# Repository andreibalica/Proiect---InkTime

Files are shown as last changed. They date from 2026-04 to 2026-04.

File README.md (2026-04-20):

# InkTime Smartwatch - Documentatie Hardware

Acest repository contine fisierele de proiectare hardware (scheme electronice, layout PCB) pentru InkTime, un smartwatch open-source. Proiectul este axat pe eficientizarea consumului energetic si integrarea unui afisaj bi-stabil.

## 1. Principiu de Functionare si Eficienta Energetica

Sistemul elimina limitarile de autonomie specifice smartwatch-urilor clasice prin utilizarea unui ecran tip E-Paper (electroforetic). 

Datorita proprietatii de bi-stabilitate, matricea display-ului isi pastreaza starea fara a necesita alimentare continua. Consumul de energie are loc exclusiv pe durata ciclului de refresh (schimbarea informatiei afisate). Aceasta caracteristica tehnica permite microcontroller-ului sa ramana in modul "Deep Sleep" pe perioade lungi, asigurand o autonomie extinsa si eliminand totodata necesitatea iluminarii de fundal (Backlight).

## 2. Subsisteme Componente

Arhitectura sistemului este impartita in urmatoarele blocuri functionale majore:

* **Microcontroller (MCU):** Implementat in jurul SoC-ului nRF52840 (Nordic Semiconductor). Ofera suport nativ pentru protocolul Bluetooth 5.0 (BLE) si asigura procesarea generala, gestionand atat magistralele de date, cat si modurile de operare ultra-low power.
* **Power Management Unit (PMU):**
  * **Circuit de Incarcare:** Controller dedicat pe portul USB-C, echipat cu protectie la supratensiune si descarcari electrostatice (ESD / diode TVS).
  * **Regulator DC/DC:** Ofera o tensiune stabilizata de 3.3V necesara liniilor digitale, compensand variatiile de tensiune ale acumulatorului LiPo.
  * **Fuel Gauge:** Integrat de masurare a capacitatii reziduale (State of Charge). Citeste datele celulei LiPo fara a necesita un rezistor de shunt si raporteaza valorile prin I2C.
* **Senzoristica si Interfata Utilizator:**
  * **IMU (Inertial Measurement Unit):** Senzor accelerometric utilizat pentru numararea pasilor si detectia gestului de activare a ecranului.
  * **Driver Haptic:** Asigura comanda prin PWM a motorului de vibratii pentru generarea alertelor tactile.
  * **Input Hardware:** Trei butoane mecanice conectate pe porturile GPIO pentru operarea dispozitivului.

## 3. Interfete de Comunicatie

Comunicatia in interiorul sistemului este structurata pentru a separa transferul de date rapid de citirea senzorilor:

* **Magistrala SPI:** Alocata strict modulului E-Paper. Faciliteaza transferul rapid de date catre controller-ul de display pe parcursul refresh-ului.
* **Magistrala I2C:** Utilizata ca port comun de comunicatie pentru senzorul IMU, integratul Fuel Gauge si driver-ul haptic.
* **Semnale EXTI (Intreruperi):** Butoanele mecanice si pinul de interrupt al senzorului IMU trezesc in mod direct microcontroller-ul din starea de repaus atunci cand se inregistreaza un eveniment fizic.

## 4. Note de Fabricatie si Asamblare (PCBA)

Acest repository include fisierele de productie (Gerber / Pick and Place) si lista de materiale (BOM) necesare pentru fabricarea placii. Pentru a garanta functionarea la parametri optimi a ansamblului, procesul de productie trebuie sa respecte urmatoarele cerinte tehnice:

* **Grosime Substrat:** Placa de baza (PCB) trebuie fabricata cu o grosime stricta de 1.0mm. Utilizarea grosimii standard de 1.6mm va compromite asamblarea mecanica in interiorul carcasei printate 3D.
* **Optimizare PCBA:** Designul a fost conceput pentru a facilita productia automatizata. Toate componentele SMD sunt plasate exclusiv pe stratul superior (TOP Layer), reducand atat complexitatea, cat si costurile procesului de asamblare.
* **Integritate RF si Rutare:** S-a implementat tehnica de "via stitching" intre planurile de masa (TOP si BOTTOM) in vecinatatea circuitului radio. Acest detaliu este critic pentru performanta antenei ceramice la 2.4GHz. De asemenea, erorile de tip "Board Outline Clearance" din zona antenei sunt intentionate, antena necesitand lipsa totala a cuprului pe layerele adiacente.

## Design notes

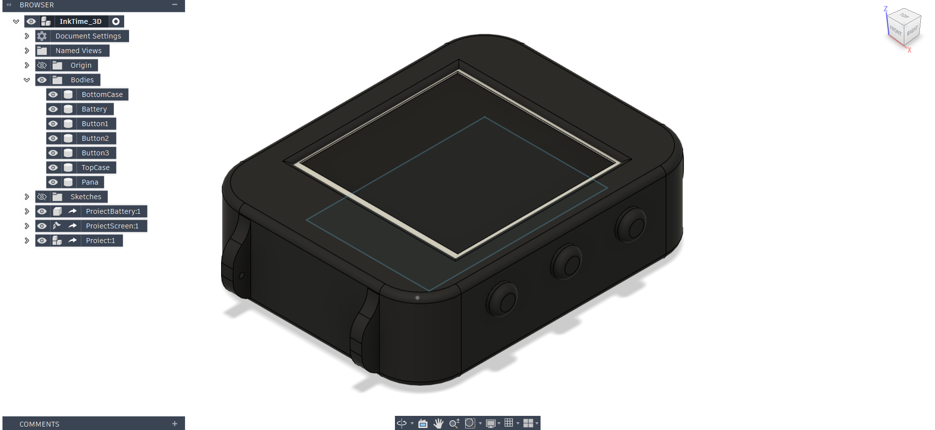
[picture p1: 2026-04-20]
Images/3DModel_withCase.png

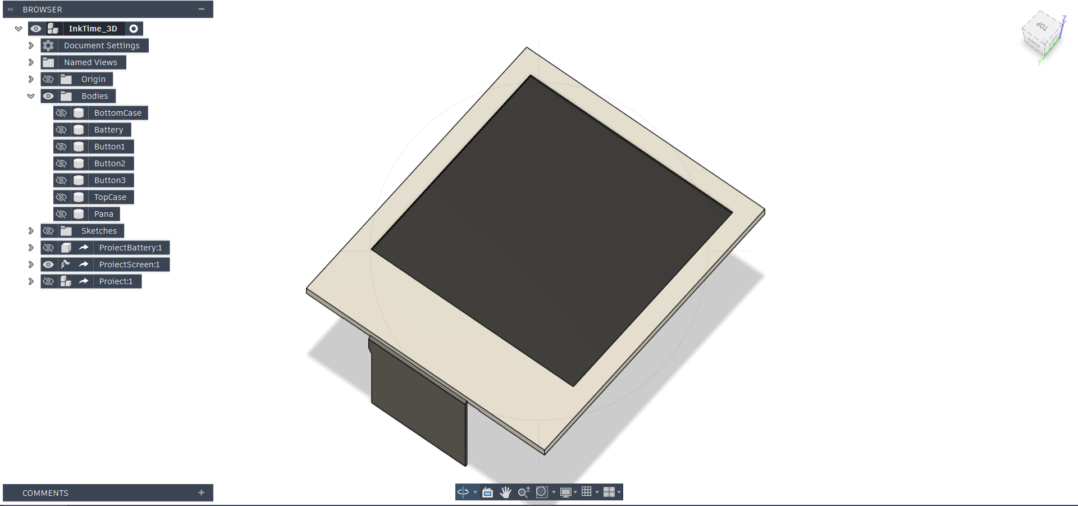
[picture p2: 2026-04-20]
Images/3DScreen.png

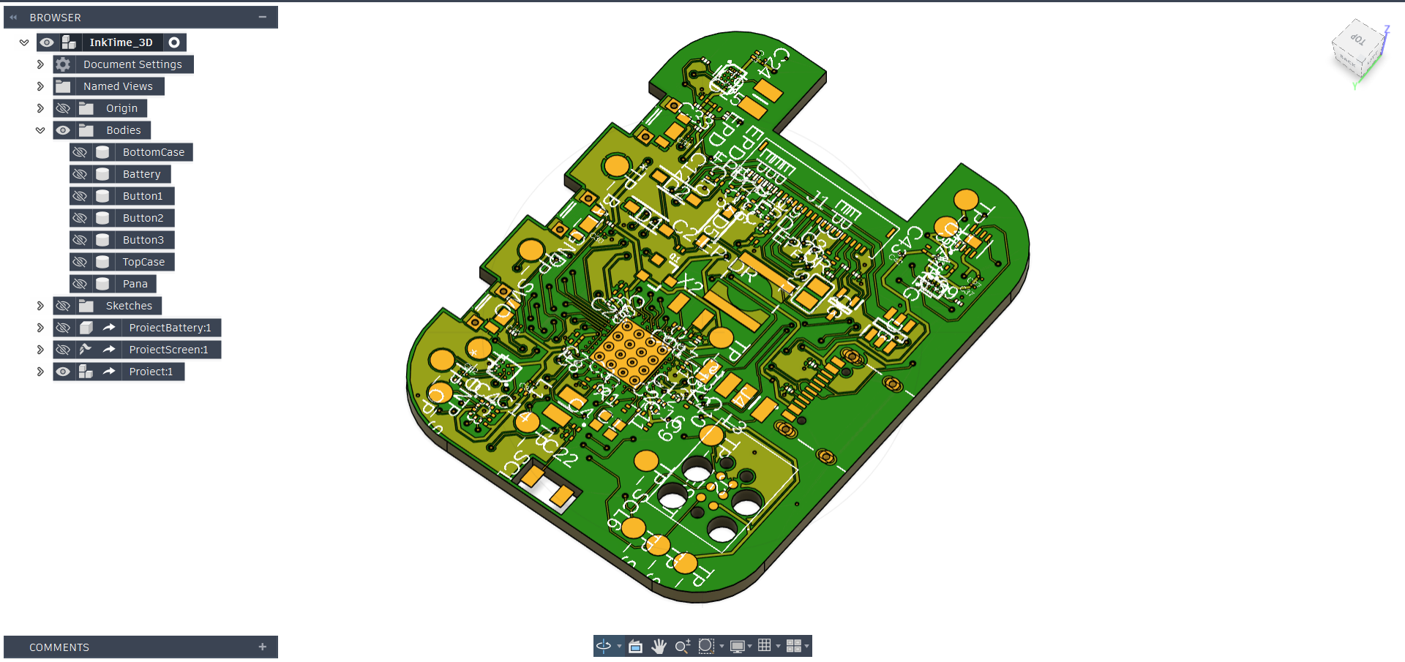
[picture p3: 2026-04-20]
Images/3DPCB.png

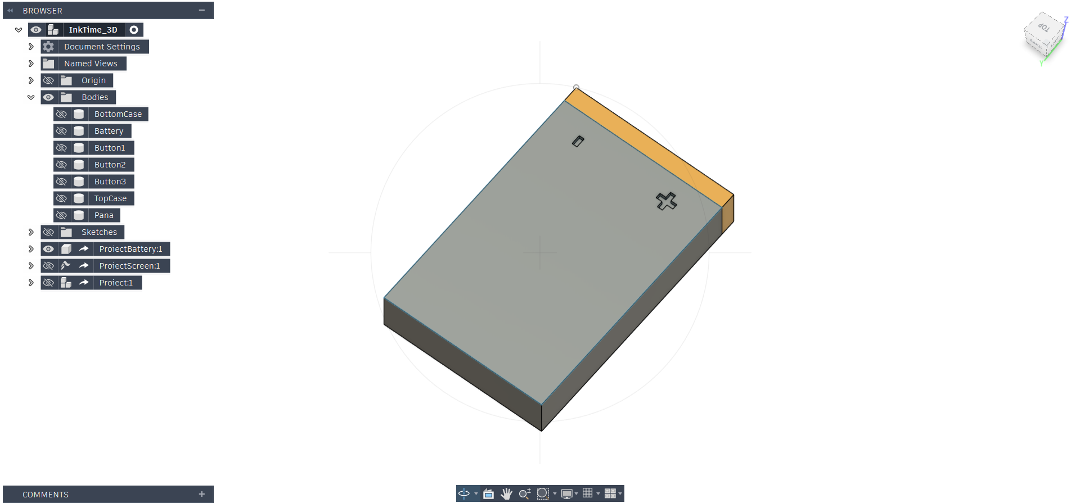
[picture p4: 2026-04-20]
Images/Battery.png

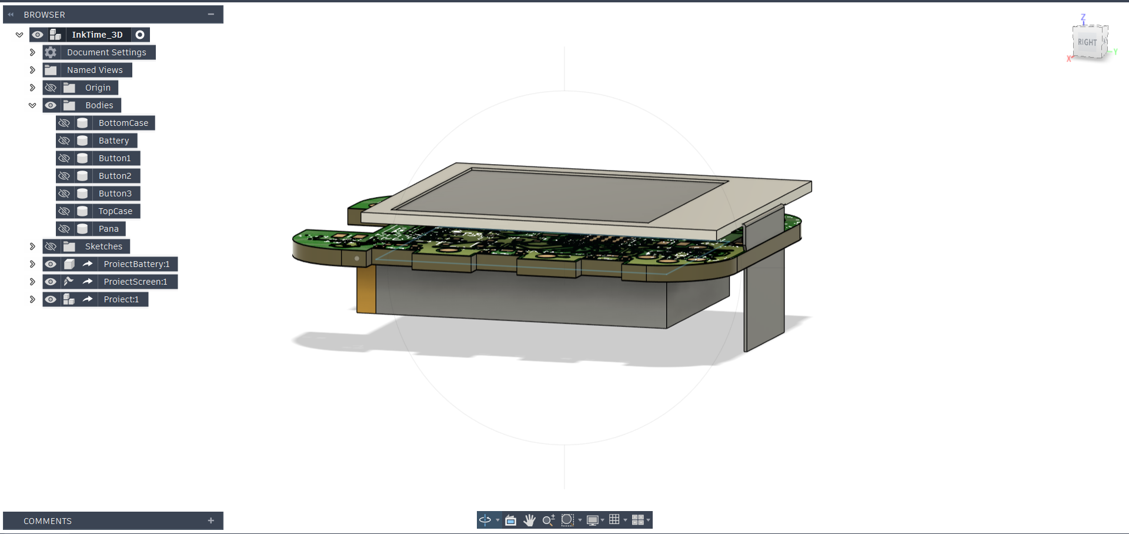
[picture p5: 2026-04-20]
Images/3DModel_withoutCase.png

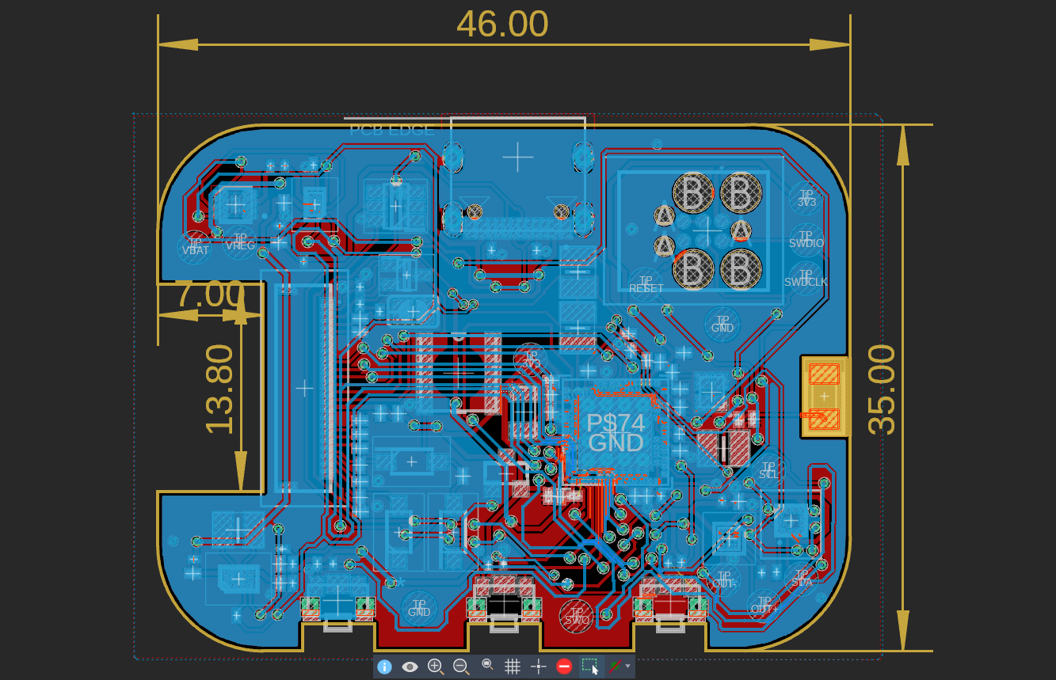
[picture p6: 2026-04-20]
Images/PCB_Bottom.png

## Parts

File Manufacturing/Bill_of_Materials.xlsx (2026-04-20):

Name | Proiect
Exported by | andrei.balica@stud.acs.upb.ro
Time of Export | 20/04/2026 14:44
Reference Designators | Quantity | Description | Package | Value | Manufacturer | Manufacturer Part Number | Vendor | Vendor Part Number | Top/Bottom
 | 1 | PCB Board | Board
ANT1 | 1 | Antennas 2.45GHz ANTENNA | 2450AT18B100E_ANTC3216X140N | 2450AT18B100E |  |  |  |  | Top
C1, C2, C17, C18 | 4 | Generic chip capacitor | NORDIC_NRF_3_RESC0201_L | 12pF |  |  |  |  | Top
C1-EP-DR, C24, C39 | 3 | Generic chip capacitor | NORDIC_NRF_3_RESC0201_L | 10uF |  |  |  |  | Top
C2-EP-DR | 1 | Generic chip capacitor | NORDIC_NRF_3_RESC0201_L | 4.7uF/25V |  |  |  |  | Top
C3, C4 | 2 | Generic chip capacitor | NORDIC_NRF_3_RESC0201_L | 1pF |  |  |  |  | Top
C5, C7, C8, C12 | 4 | Generic chip capacitor | NORDIC_NRF_3_RESC0201_L | 100nF |  |  |  |  | Top
C6, C14, C20, C21, C43 | 5 | Generic chip capacitor | NORDIC_NRF_3_RESC0201_L | 4.7uF |  |  |  |  | Top
C9, C25, C33 | 3 | Generic chip capacitor | NORDIC_NRF_3_RESC0201_L | 22uF |  |  |  |  | Top
C9\ | 1 | Generic chip capacitor | NORDIC_NRF_3_RESC0201_L | 820pF |  |  |  |  | Top
C10, C13, C22 | 3 | Generic chip capacitor | NORDIC_NRF_3_RESC0201_L | N.C. |  |  |  |  | Top
C11 | 1 | Generic chip capacitor | NORDIC_NRF_3_RESC0201_L | 100pF |  |  |  |  | Top
C15 | 1 | Generic chip capacitor | NORDIC_NRF_3_RESC0201_L | 1.0uF |  |  |  |  | Top
C16 | 1 | Generic chip capacitor | NORDIC_NRF_3_RESC0201_L | 47nF |  |  |  |  | Top
C23, C27, C34, C42 | 4 | Check availability | CAPC0201X13N | 0.1uF |  |  |  |  | Top
C29, C30, C31, C32, C37, C38 | 6 | Check availability | CAPC0201X13N | 1uF |  |  |  |  | Top
D2, D4, D5 | 3 | ON SEMICONDUCTOR - MBR0530 - DIODE, SCHOTTKY, 0.5A, 30V, SOD-123 | SOD3716X135N | MBR0530 |  |  |  |  | Top
D3 | 1 | Low Cap. ESD Protection Auto SOT-23-6 STMicroelectronics USBLC6-2SC6Y, Dual Uni-Directional TVS Diode Array, 6-Pin SOT-23 | SOT95P280X145-6N | USBLC6-2SC6Y |  |  |  |  | Top
EPD_C1, EPD_C2, EPD_C6, EPD_C7, EPD_C8, EPD_C9, EPD_C10, EPD_C11, EPD_C12 | 9 | Generic chip capacitor | NORDIC_NRF_3_RESC0201_L | 1uF/50V |  |  |  |  | Top
EPD_C3 | 1 | Generic chip capacitor | NORDIC_NRF_3_RESC0201_L | 0.1uF/50V |  |  |  |  | Top
IC1 | 1 | Charger IC Lithium Ion/Polymer, Lithium Iron Phosphate 8-DSBGA (1.6x1.1) | BQ25180YBGR_BGA8C40P2X4_100X155X50 | BQ25180YBGR_BQ25180YBGR |  |  |  |  | Top
IC3 | 1 | Accelerometers Triaxial low-g 12bit Acceleration Sensor | BMA423_BMA423 | BMA421 |  |  |  |  | Top
IC4 | 1 | Haptic Driver for ERM/LRA with Built-In Library and Smart Loop Architecture | DRV2605YZFR_BGA9C50P3X3_144X144X62 | DRV2605YZFR |  |  |  |  | Top
IC9 | 1 | Buck-Boost Regulator Positive Output Step-Up/Step-Down I2C DC-DC Controller IC 15-WL-CSP (BSC) (1.4x2.3) | RT6160AWSC_BGA15C40P3X5_140X230X60 | RT6160AWSC |  |  |  |  | Top
J1 | 1 | FFC & FPC Connectors 0.5mm FPC RA SMT Dual Contact 24Ckt | 503480-2400_5034802400 | 503480-2400 |  |  |  |  | Top
J2 | 1 | CABLE ADAPTER 6 POS | TC2030-IDC_TC2030IDC | TC2030-IDC |  |  |  |  | Top
J4 | 1 | Check availability | KINGHELM_KH-TYPE-C-16P | KH-TYPE-C-16P |  |  |  |  | Top
L1 | 1 | SMD / SMT Inductors (Coils), L=0.47?H, L x W x T : | MLP2016SR47MT0S1_INDC2016X100N | 3.9nH |  |  |  |  | Top
L2 | 1 | SMD / SMT Inductors (Coils), L=0.47?H, L x W x T : | MLP2016SR47MT0S1_INDC2016X100N | 10uH |  |  |  |  | Top
L3 | 1 | SMD / SMT Inductors (Coils), L=0.47?H, L x W x T : | MLP2016SR47MT0S1_INDC2016X100N | 15nH |  |  |  |  | Top
L5 | 1 |  | ESP32_C6_LIBRARY_2_IND_4828-WE-TPC_WRE | 68uH |  |  |  |  | Top
L7 | 1 | SMD / SMT Inductors (Coils), L=0.47?H, L x W x T : | MLP2016SR47MT0S1_INDC2016X100N | FTC252012SR47MBCA |  |  |  |  | Top
Q1 | 1 | P-channel MOSFETs | ESP32_WROVER_SPARKFUN-DISCRETESEMI_SOT23-3 | 20V/4.2A/52mΩ/1.4W |  |  |  |  | Top
Q3 | 1 | MOSFET N-Ch 30V 1.5A TrenchFET SC70 Vishay Si1308EDL-T1-GE3 N-channel MOSFET Transistor, 1.5 A, 30 V, 3-Pin SC-70 | SOT65P210X110-3N | SI1308EDL-T1-GE3 |  |  |  |  | Top
R_PWR_EPD, R1, R2_EP_DR, R5, R7, R8 | 6 | 7.68k 0201 Thin Film Surface Mount Fixed Resistor +/-0.5% 0.031W CPF0201D7K68C1 | R0201 | 10K |  |  |  |  | Top
R_TYPE_SEL | 1 | 7.68k 0201 Thin Film Surface Mount Fixed Resistor +/-0.5% 0.031W CPF0201D7K68C1 | R0201 | 2.2 |  |  |  |  | Top
R1_EP_DR | 1 | 7.68k 0201 Thin Film Surface Mount Fixed Resistor +/-0.5% 0.031W CPF0201D7K68C1 | R0201 | 0.47 |  |  |  |  | Top
R1_USB, R2_USB | 2 | 7.68k 0201 Thin Film Surface Mount Fixed Resistor +/-0.5% 0.031W CPF0201D7K68C1 | R0201 | 5K1 |  |  |  |  | Top
R2, R3, R4 | 3 | 7.68k 0201 Thin Film Surface Mount Fixed Resistor +/-0.5% 0.031W CPF0201D7K68C1 | R0201 | 0 |  |  |  |  | Top
R17, R18 | 2 | 7.68k 0201 Thin Film Surface Mount Fixed Resistor +/-0.5% 0.031W CPF0201D7K68C1 | R0201 | 3K3 |  |  |  |  | Top
SJ1 | 1 | SMD solder JUMPER | JUMPER_SJ |  |  |  |  |  | Top
SW_DN, SW_ENT, SW_UP | 3 |  | SW_EVP-AKE31A_PAN | 2025-10-22_07-23-44_LIBRARY_EVP-AKE31ASW_EVP-AKE31A_PAN |  |  |  |  | Top
TP_3.3V, TP_3V3, TP_BAT_GND, TP_ON, TP_OP, TP_RESET, TP_SCL, TP_SCL6, TP_SDA, TP_SWDCLK, TP_SWDIO, TP_SWO, TP_VBAT, TP_VREG | 14 | Test pad | HECTOR_WATCH_1_TP20R | HECTOR_WATCH_1_TPTP20R |  |  |  |  | Top
U1 | 1 | nRF52840 | NORDIC_NRF_4_AQFN50P700X700X85_HS-74N | NRF52840_QF |  |  |  |  | Top
U3 | 1 | Check availability | SON50P200X200X80-9N | MAX17048G+T10 |  |  |  |  | Top
X1 | 1 |  | NORDIC_NRF_BT-XTAL_2016_N | 32MHz |  |  |  |  | Top
X2 | 1 |  | NORDIC_NRF_1_XTAL_3215_N | 32.768kHz |  |  |  |  | Top

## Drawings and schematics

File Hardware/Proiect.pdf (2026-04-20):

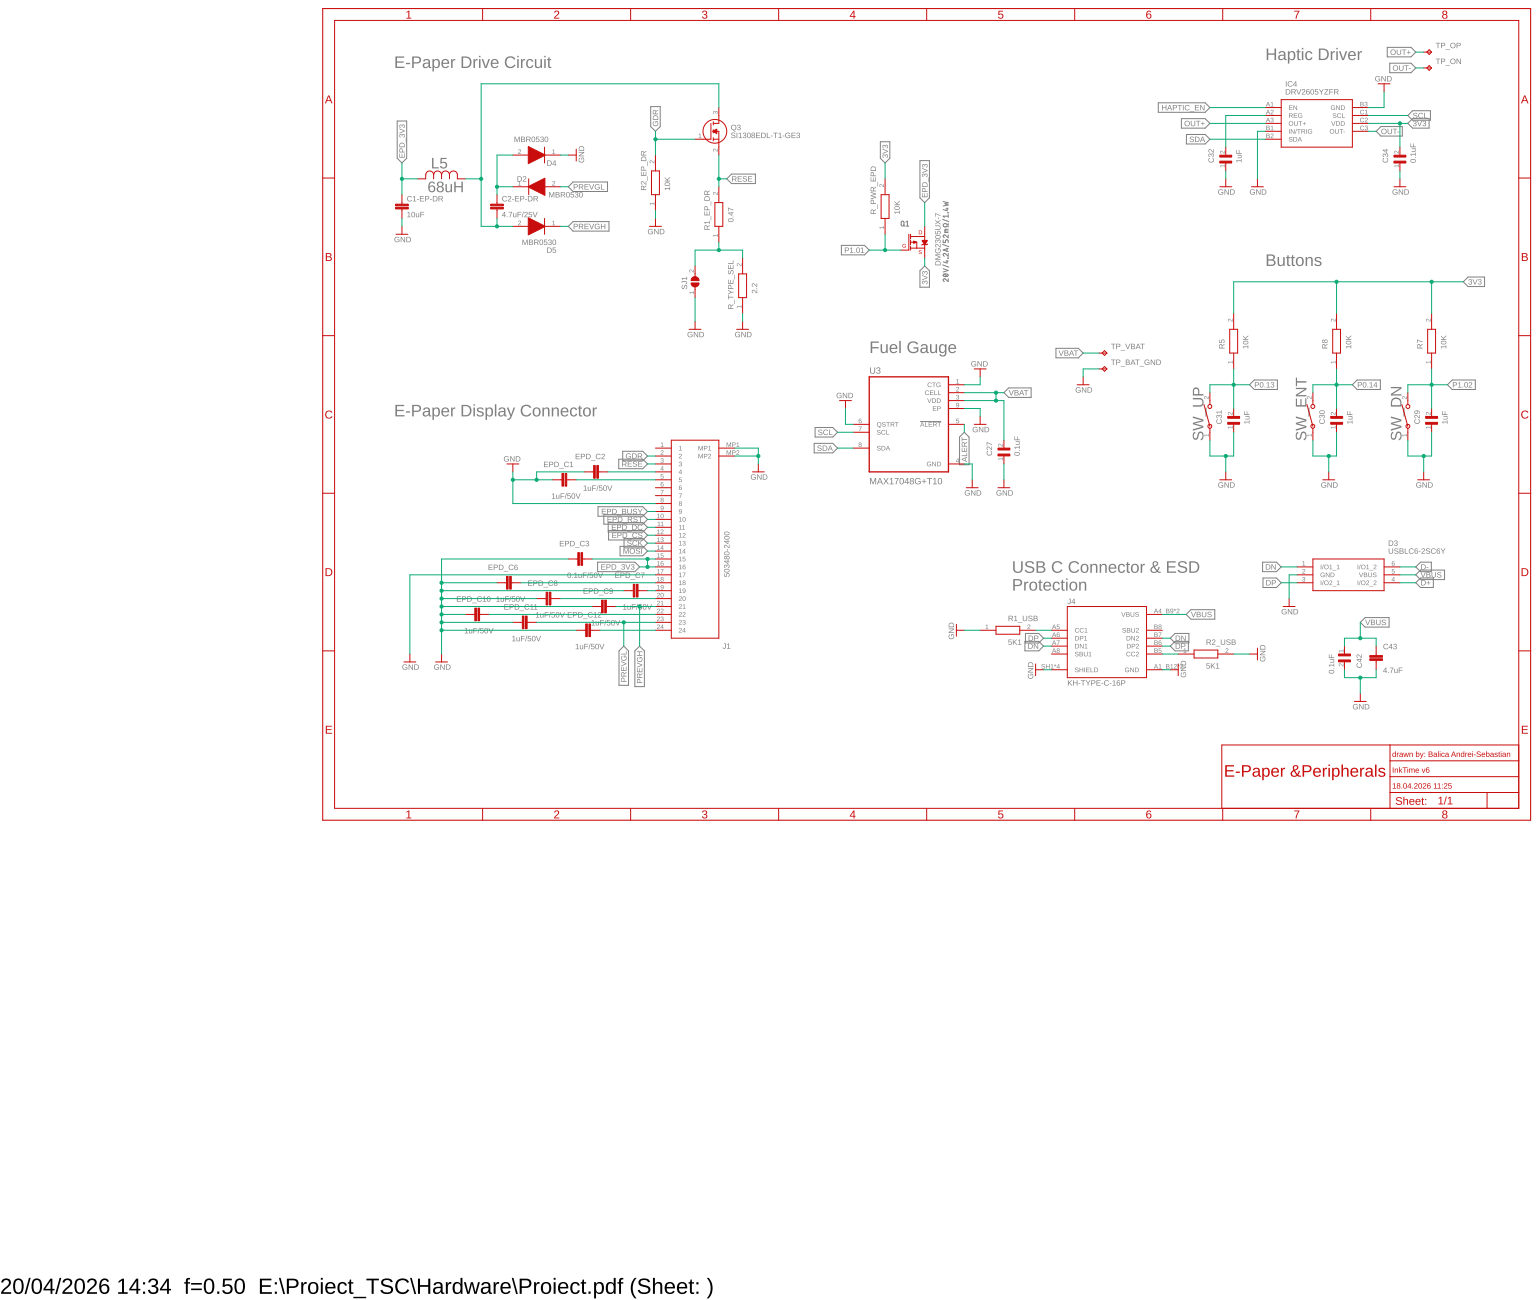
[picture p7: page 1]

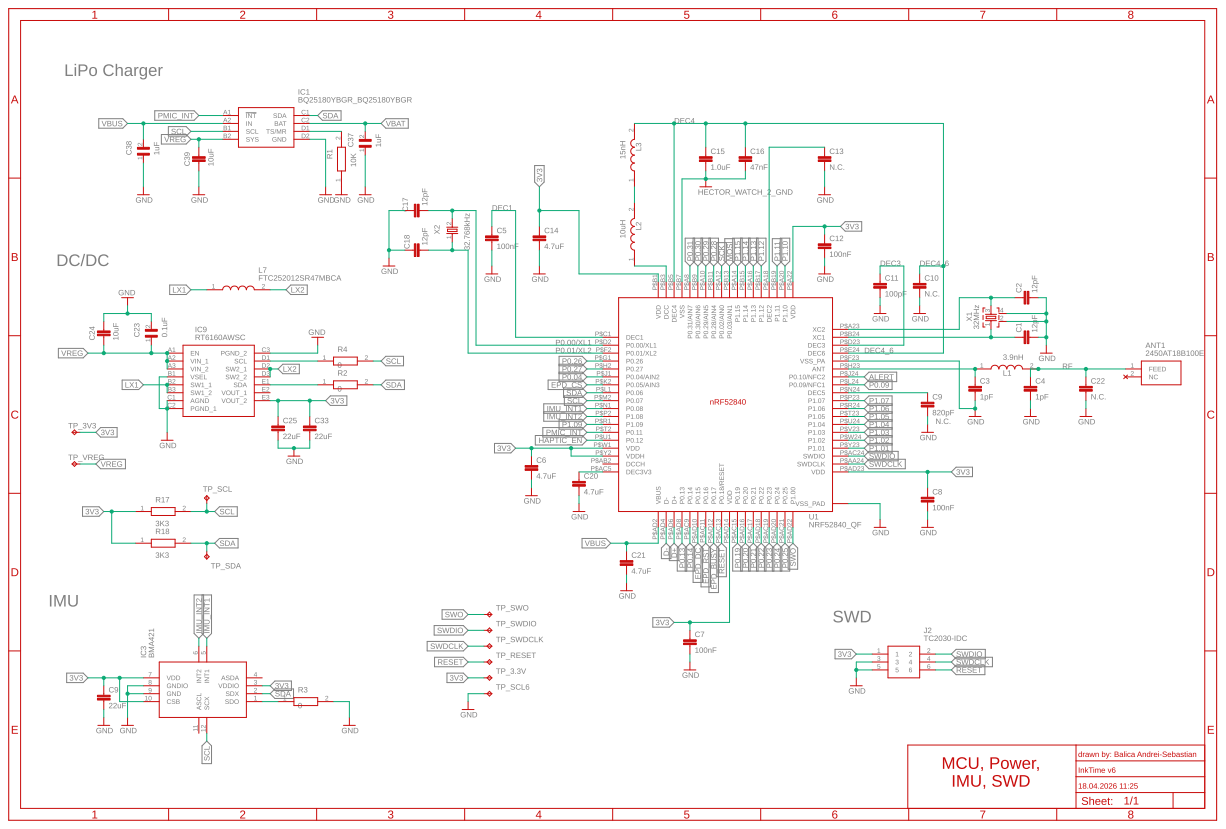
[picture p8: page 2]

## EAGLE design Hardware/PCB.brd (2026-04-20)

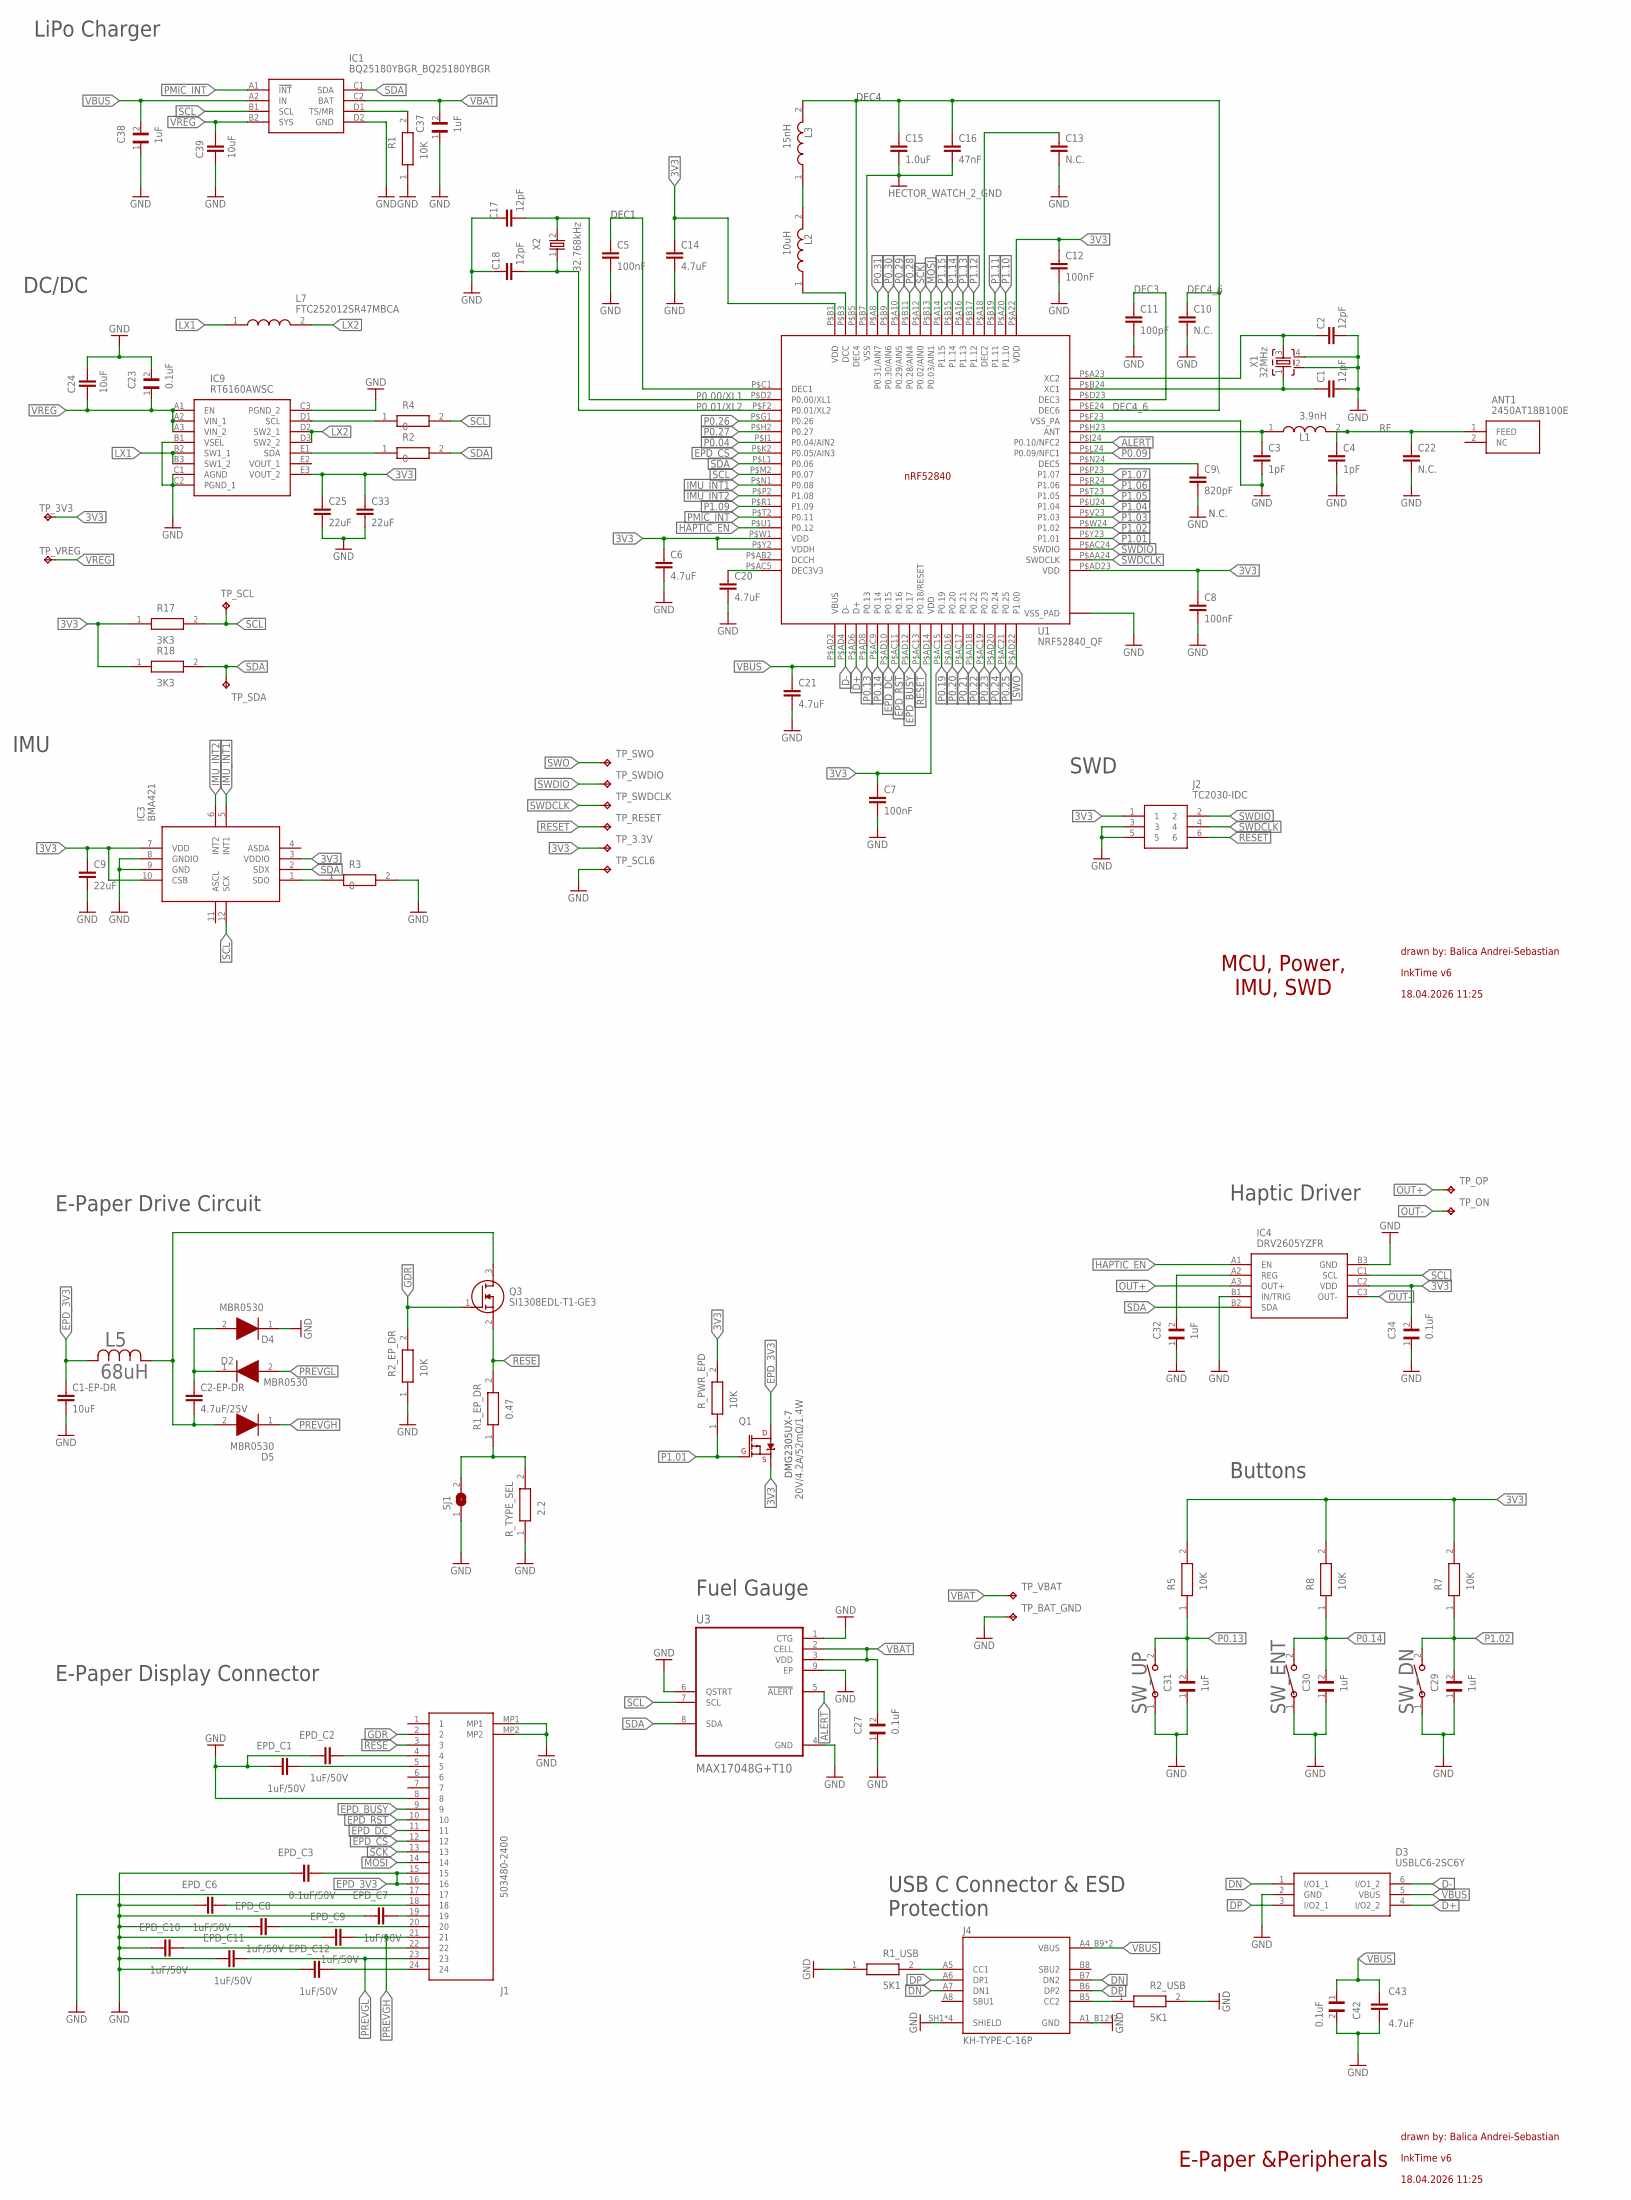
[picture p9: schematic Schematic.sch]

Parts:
ANT1: 2450AT18B100E; 2450AT18B100E_ANTC3216X140N
C1, C2, C17, C18: 12pF; NORDIC_NRF_3_RESC0201_L
C1-EP-DR, C24, C39: 10uF; NORDIC_NRF_3_RESC0201_L
C2-EP-DR: 4.7uF/25V; NORDIC_NRF_3_RESC0201_L
C3, C4: 1pF; NORDIC_NRF_3_RESC0201_L
C5, C7, C8, C12: 100nF; NORDIC_NRF_3_RESC0201_L
C6, C14, C20, C21, C43: 4.7uF; NORDIC_NRF_3_RESC0201_L
C9, C25, C33: 22uF; NORDIC_NRF_3_RESC0201_L
C9\: 820pF; NORDIC_NRF_3_RESC0201_L
C10, C13, C22: N.C.; NORDIC_NRF_3_RESC0201_L
C11: 100pF; NORDIC_NRF_3_RESC0201_L
C15: 1.0uF; NORDIC_NRF_3_RESC0201_L
C16: 47nF; NORDIC_NRF_3_RESC0201_L
C23, C27, C34, C42: 0.1uF; GRM011R60J152KE01L_2_CAPC0201X13N
C29, C30, C31, C32, C37, C38: 1uF; GRM011R60J152KE01L_2_CAPC0201X13N
D2, D4, D5: MBR0530; ESP32_C6_LIBRARY_5_SOD3716X135N
D3: USBLC6-2SC6Y; ESP32_C6_LIBRARY_3_SOT95P280X145-6N
EPD_C1, EPD_C2, EPD_C6, EPD_C7, EPD_C8, EPD_C9, EPD_C10, EPD_C11, EPD_C12: 1uF/50V; NORDIC_NRF_3_RESC0201_L
EPD_C3: 0.1uF/50V; NORDIC_NRF_3_RESC0201_L
IC1: BQ25180YBGR_BQ25180YBGR; BQ25180YBGR_BGA8C40P2X4_100X155X50
IC3: BMA421; BMA423_BMA423
IC4: DRV2605YZFR; DRV2605YZFR_BGA9C50P3X3_144X144X62
IC9: RT6160AWSC; RT6160AWSC_BGA15C40P3X5_140X230X60
J1: 503480-2400; 503480-2400_5034802400
J2: TC2030-IDC; TC2030-IDC_TC2030IDC
J4: KH-TYPE-C-16P; KH-TYPE-C-16P_KINGHELM_KH-TYPE-C-16P
L1: 3.9nH; MLP2016SR47MT0S1_INDC2016X100N
L2: 10uH; MLP2016SR47MT0S1_INDC2016X100N
L3: 15nH; MLP2016SR47MT0S1_INDC2016X100N
L5: 68uH; ESP32_C6_LIBRARY_2_IND_4828-WE-TPC_WRE
L7: FTC252012SR47MBCA; MLP2016SR47MT0S1_INDC2016X100N
Q1: 20V/4.2A/52mΩ/1.4W; ESP32_C6_LIBRARY_4_ESP32_C6_LIBRARY_4_ESP32_C6_LIBRARY_4_ES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
Q3: SI1308EDL-T1-GE3; ESP32_C6_LIBRARY_6_SOT65P210X110-3N
R1, R2_EP_DR, R5, R7, R8: 10K; ERA-1AEB3401C_0201
R1_EP_DR: 0.47; ERA-1AEB3401C_0201
R1_USB, R2_USB: 5K1; ERA-1AEB3401C_0201
R2, R3, R4: 0; ERA-1AEB3401C_0201
R17, R18: 3K3; ERA-1AEB3401C_0201
R_PWR_EPD: 10K; ERA-1AEB3401C_0201
R_TYPE_SEL: 2.2; ERA-1AEB3401C_0201
SJ1: ESP32_C6_LIBRARY_7_JUMPER_SJ
SW_DN: 2025-10-22_07-23-44_LIBRARY_EVP-AKE31ASW_EVP-AKE3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; 2025-10-22_07-23-44_LIBRARY_SW_EVP-AKE31A_PAN
SW_ENT: 2025-10-22_07-23-44_LIBRARY_EVP-AKE31ASW_EVP-AKE3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; 2025-10-22_07-23-44_LIBRARY_SW_EVP-AKE31A_PAN
SW_UP: 2025-10-22_07-23-44_LIBRARY_EVP-AKE31ASW_EVP-AKE3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; 2025-10-22_07-23-44_LIBRARY_SW_EVP-AKE31A_PAN
TP_3.3V, TP_3V3: HECTOR_WATCH_1_TPTP20R; HECTOR_WATCH_1_TP20R
TP_BAT_GND: HECTOR_WATCH_1_TPTP20R; HECTOR_WATCH_1_TP20R
TP_ON: HECTOR_WATCH_1_TPTP20R; HECTOR_WATCH_1_TP20R
TP_OP: HECTOR_WATCH_1_TPTP20R; HECTOR_WATCH_1_TP20R
TP_RESET: HECTOR_WATCH_1_TPTP20R; HECTOR_WATCH_1_TP20R
TP_SCL, TP_SCL6: HECTOR_WATCH_1_TPTP20R; HECTOR_WATCH_1_TP20R
TP_SDA: HECTOR_WATCH_1_TPTP20R; HECTOR_WATCH_1_TP20R
TP_SWDCLK: HECTOR_WATCH_1_TPTP20R; HECTOR_WATCH_1_TP20R
TP_SWDIO: HECTOR_WATCH_1_TPTP20R; HECTOR_WATCH_1_TP20R
TP_SWO: HECTOR_WATCH_1_TPTP20R; HECTOR_WATCH_1_TP20R
TP_VBAT: HECTOR_WATCH_1_TPTP20R; HECTOR_WATCH_1_TP20R
TP_VREG: HECTOR_WATCH_1_TPTP20R; HECTOR_WATCH_1_TP20R
U1: NRF52840_QF; NORDIC_NRF_4_AQFN50P700X700X85_HS-74N
U3: MAX17048G+T10; ESP32_C6_LIBRARY_SON50P200X200X80-9N
X1: 32MHz; NORDIC_NRF_BT-XTAL_2016_N
X2: 32.768kHz; NORDIC_NRF_1_XTAL_3215_N

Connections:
3V3: C6.1, C7.1, C8.1, C9.1, C12.1, C14.1, C25.1, C33.1, C34.2, IC3.3 (VDDIO), IC3.7 (VDD), IC3.10 (CSB), IC4.C2 (VDD), IC9.E3 (VOUT_2), J2.1, Q1.2 (S), R5.2, R7.2, R8.2, R17.1, R18.1, R_PWR_EPD.2, TP_3.3V.TP, TP_3V3.TP, U1.P$A22 (VDD), U1.P$AD14 (VDD), U1.P$AD23 (VDD), U1.P$B1 (VDD), U1.P$W1 (VDD), U1.P$Y2 (VDDH)
ALERT: U1.P$J24 (P0.10/NFC2), U3.5 (!ALERT)
D+: D3.4 (I/O2_2), U1.P$AD6 (D+)
D-: D3.6 (I/O1_2), U1.P$AD4 (D-)
DEC3: C11.1, U1.P$D23 (DEC3)
DEC4_6: C10.1, C15.1, C16.1, L3.2, U1.P$B5 (DEC4), U1.P$E24 (DEC6)
DN: D3.1 (I/O1_1), J4.A7 (DN1), J4.B7 (DN2)
DP: D3.3 (I/O2_1), J4.A6 (DP1), J4.B6 (DP2)
EPD_3V3: C1-EP-DR.1, EPD_C3.2, J1.15, J1.16, L5.2, Q1.3 (D)
EPD_BUSY: J1.9, U1.P$AD12 (P0.17)
EPD_CS: J1.12, U1.P$K2 (P0.05/AIN3)
EPD_DC: J1.11, U1.P$AD10 (P0.15)
EPD_RST: J1.10, U1.P$AC11 (P0.16)
GDR: J1.2, Q3.1 (G), R2_EP_DR.2
GND: C1.2, C1-EP-DR.2, C2.2, C3.2, C4.2, C5.2, C6.2, C7.2, C8.2, C9.2, C9\.2, C10.2, C11.2, C12.2, C13.2, C14.2, C15.2, C16.2, C17.1, C18.2, C20.2, C21.2, C22.2, C23.2, C24.1, C25.2, C27.1, C29.1, C30.1, C31.1, C32.1, C33.2, C34.1, C37.1, C38.1, C39.2, C42.2, C43.2, D3.2 (GND), D4.1 (K), EPD_C1.1, EPD_C2.1, EPD_C3.1, EPD_C6.1, EPD_C7.1, EPD_C8.1, EPD_C9.1, EPD_C10.1, EPD_C11.1, EPD_C12.1, IC1.D2 (GND), IC3.8 (GNDIO), IC3.9 (GND), IC4.B1 (IN/TRIG), IC4.B3 (GND), IC9.B1 (VSEL), IC9.C1 (AGND), IC9.C2 (PGND_1), IC9.C3 (PGND_2), J1.8, J1.17, J1.MP1, J1.MP2, J2.3, J2.5, J4.A1_B12 (GND), J4.A12_B1 (GND), J4.SH1 (SHIELD), J4.SH2 (SHIELD), J4.SH3 (SHIELD), J4.SH4 (SHIELD), R1.1, R1_USB.1, R2_EP_DR.1, R2_USB.2, R3.2, R_TYPE_SEL.1, SJ1.1, SW_DN.1, SW_ENT.1, SW_UP.1, TP_BAT_GND.TP, TP_SCL6.TP, U1.P$74 (VSS_PAD), U1.P$75 (VSS_PAD), U1.P$76 (VSS_PAD), U1.P$77 (VSS_PAD), U1.P$78 (VSS_PAD), U1.P$79 (VSS_PAD), U1.P$80 (VSS_PAD), U1.P$81 (VSS_PAD), U1.P$82 (VSS_PAD), U1.P$83 (VSS_PAD), U1.P$84 (VSS_PAD), U1.P$85 (VSS_PAD), U1.P$86 (VSS_PAD), U1.P$87 (VSS_PAD), U1.P$88 (VSS_PAD), U1.P$89 (VSS_PAD), U1.P$90 (VSS_PAD), U1.P$B7 (VSS), U1.P$F23 (VSS_PA), U3.1 (CTG), U3.4 (GND), U3.6 (QSTRT), U3.9 (EP), X1.2, X1.4
HAPTIC_EN: IC4.A1 (EN), U1.P$U1 (P0.12)
IMU_INT1: IC3.5 (INT1), U1.P$N1 (P0.08)
IMU_INT2: IC3.6 (INT2), U1.P$P2 (P1.08)
LX1: IC9.B2 (SW1_1), IC9.B3 (SW1_2), L7.1
LX2: IC9.D2 (SW2_1), IC9.D3 (SW2_2), L7.2
MOSI: J1.14, U1.P$B13 (P0.03/AIN1)
unnamed: C13.1, U1.P$A18 (DEC2)
unnamed: C5.1, U1.P$C1 (DEC1)
unnamed: IC1.D1 (TS/MR), R1.2
unnamed: IC9.D1 (SCL), R4.1
unnamed: IC9.E1 (SDA), R2.1
unnamed: L2.1, U1.P$B3 (DCC)
unnamed: L2.2, L3.1
unnamed: C20.1, U1.P$AC5 (DEC3V3)
unnamed: C3.1, L1.1, U1.P$H23 (ANT)
unnamed: C9\.1, U1.P$N24 (DEC5)
unnamed: C2.1, U1.P$A23 (XC2), X1.3
unnamed: C1.1, U1.P$B24 (XC1), X1.1
unnamed: C18.1, U1.P$F2 (P0.01/XL2), X2.1
unnamed: C2-EP-DR.2, D5.2 (A), L5.1, Q3.3 (D)
unnamed: C2-EP-DR.1, D2.1 (K), D4.2 (A)
unnamed: EPD_C2.2, J1.4
unnamed: EPD_C6.2, J1.18
unnamed: R1_EP_DR.1, R_TYPE_SEL.2, SJ1.2
unnamed: IC3.1 (SDO), R3.1
unnamed: EPD_C1.2, J1.5
unnamed: EPD_C7.2, J1.19
unnamed: EPD_C8.2, J1.20
unnamed: EPD_C10.2, J1.22
unnamed: EPD_C12.2, J1.24
unnamed: C32.2, IC4.A2 (REG)
unnamed: J4.A5 (CC1), R1_USB.2
unnamed: J4.B5 (CC2), R2_USB.1
OUT+: IC4.A3 (OUT+), TP_OP.TP
OUT-: IC4.C3 (OUT-), TP_ON.TP
P0.00/XL1: C17.2, U1.P$D2 (P0.00/XL1), X2.2
P0.04: U1.P$J1 (P0.04/AIN2)
P0.09: U1.P$L24 (P0.09/NFC1)
P0.13: C31.2, R5.1, SW_UP.2, U1.P$AD8 (P0.13)
P0.14: C30.2, R8.1, SW_ENT.2, U1.P$AC9 (P0.14)
P0.19: U1.P$AC15 (P0.19)
P0.20: U1.P$AD16 (P0.20)
P0.21: U1.P$AC17 (P0.21)
P0.22: U1.P$AD18 (P0.22)
P0.23: U1.P$AC19 (P0.23)
P0.24: U1.P$AD20 (P0.24)
P0.25: U1.P$AC21 (P0.25)
P0.26: U1.P$G1 (P0.26)
P0.27: U1.P$H2 (P0.27)
P0.28: U1.P$B11 (P0.28/AIN4)
P0.29: U1.P$A10 (P0.29/AIN5)
P0.30: U1.P$B9 (P0.30/AIN6)
P0.31: U1.P$A8 (P0.31/AIN7)
P1.01: Q1.1 (G), R_PWR_EPD.1, U1.P$Y23 (P1.01)
P1.02: C29.2, R7.1, SW_DN.2, U1.P$W24 (P1.02)
P1.03: U1.P$V23 (P1.03)
P1.04: U1.P$U24 (P1.04)
P1.05: U1.P$T23 (P1.05)
P1.06: U1.P$R24 (P1.06)
P1.07: U1.P$P23 (P1.07)
P1.09: U1.P$R1 (P1.09)
P1.10: U1.P$A20 (P1.10)
P1.11: U1.P$B19 (P1.11)
P1.12: U1.P$B17 (P1.12)
P1.13: U1.P$A16 (P1.13)
P1.14: U1.P$B15 (P1.14)
P1.15: U1.P$A14 (P1.15)
PMIC_INT: IC1.A1 (!INT), U1.P$T2 (P0.11)
PREVGH: D5.1 (K), EPD_C9.2, J1.21
PREVGL: D2.2 (A), EPD_C11.2, J1.23
RESE: J1.3, Q3.2 (S), R1_EP_DR.2
RESET: J2.6, TP_RESET.TP, U1.P$AC13 (P0.18/RESET)
RF: ANT1.1 (FEED), C4.1, C22.1, L1.2
SCK: J1.13, U1.P$A12 (P0.02/AIN0)
SCL: IC1.B1 (SCL), IC3.12 (SCX), IC4.C1 (SCL), R4.2, R17.2, TP_SCL.TP, U1.P$M2 (P0.07), U3.7 (SCL)
SDA: IC1.C1 (SDA), IC3.2 (SDX), IC4.B2 (SDA), R2.2, R18.2, TP_SDA.TP, U1.P$L1 (P0.06), U3.8 (SDA)
SWDCLK: J2.4, TP_SWDCLK.TP, U1.P$AA24 (SWDCLK)
SWDIO: J2.2, TP_SWDIO.TP, U1.P$AC24 (SWDIO)
SWO: TP_SWO.TP, U1.P$AD22 (P1.00)
VBAT: C27.2, C37.2, IC1.C2 (BAT), TP_VBAT.TP, U3.2 (CELL), U3.3 (VDD)
VBUS: C21.1, C38.2, C42.1, C43.1, D3.5 (VBUS), IC1.A2 (IN), J4.A4_B9 (VBUS), J4.A9_B4 (VBUS), U1.P$AD2 (VBUS)
VREG: C23.1, C24.2, C39.1, IC1.B2 (SYS), IC9.A1 (EN), IC9.A2 (VIN_1), IC9.A3 (VIN_2), TP_VREG.TP

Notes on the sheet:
LiPo Charger
DC/DC
DEC1
DEC4
N.C.
IMU
SWD
E-Paper Drive Circuit
E-Paper Display Connector
DMG2305UX-7
Fuel Gauge
Haptic Driver
Buttons
USB C Connector & ESD Protection
E-Paper &Peripherals
drawn by: Balica Andrei-Sebastian
InkTime v6
18.04.2026 11:25
MCU, Power, IMU, SWD

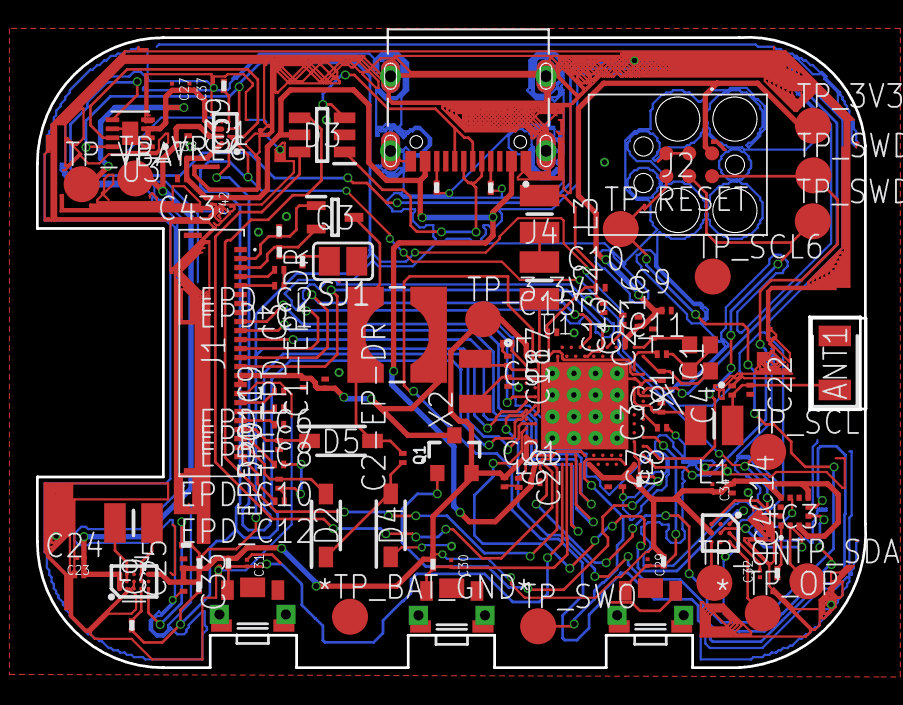
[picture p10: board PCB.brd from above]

Board: 2 copper layers, 46.0 x 35.0 mm, 105 parts (0 on the bottom side), 70 nets.

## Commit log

2026-04-10 First stage
    [PCB.brd, Schematic.sch]
2026-04-20 Final Project
    [Bill_of_Materials.xlsx, PCB.brd, Schematic.sch]

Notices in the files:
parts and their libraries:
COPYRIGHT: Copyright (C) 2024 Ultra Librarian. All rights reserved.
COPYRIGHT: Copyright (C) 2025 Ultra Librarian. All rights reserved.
